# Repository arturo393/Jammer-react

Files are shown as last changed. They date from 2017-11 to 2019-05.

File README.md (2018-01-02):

# Jammer-react
Sistem designed complement the AntiJammer of the Teltonika FMA120 devices.

## Software Protocol

1. Constantemente se revisa JAMIN.
2. If JAMIN == LOW.
 2.1 JAMOUNT  = LOW. por 90 (s)
 2.2 DOUT intercambia entre LOW y abierto duranta 90 (s).
 2.3 Se entra en modo alarma durante 90 (s)
3. Si durante el modo alarma DOORIN == Abierto
 3.1 JAMOUT = LOW durante5 minutos despues que termine el modo alarma

## Documentation
1. Flow diagram of the software.
2. Bitácora
3.

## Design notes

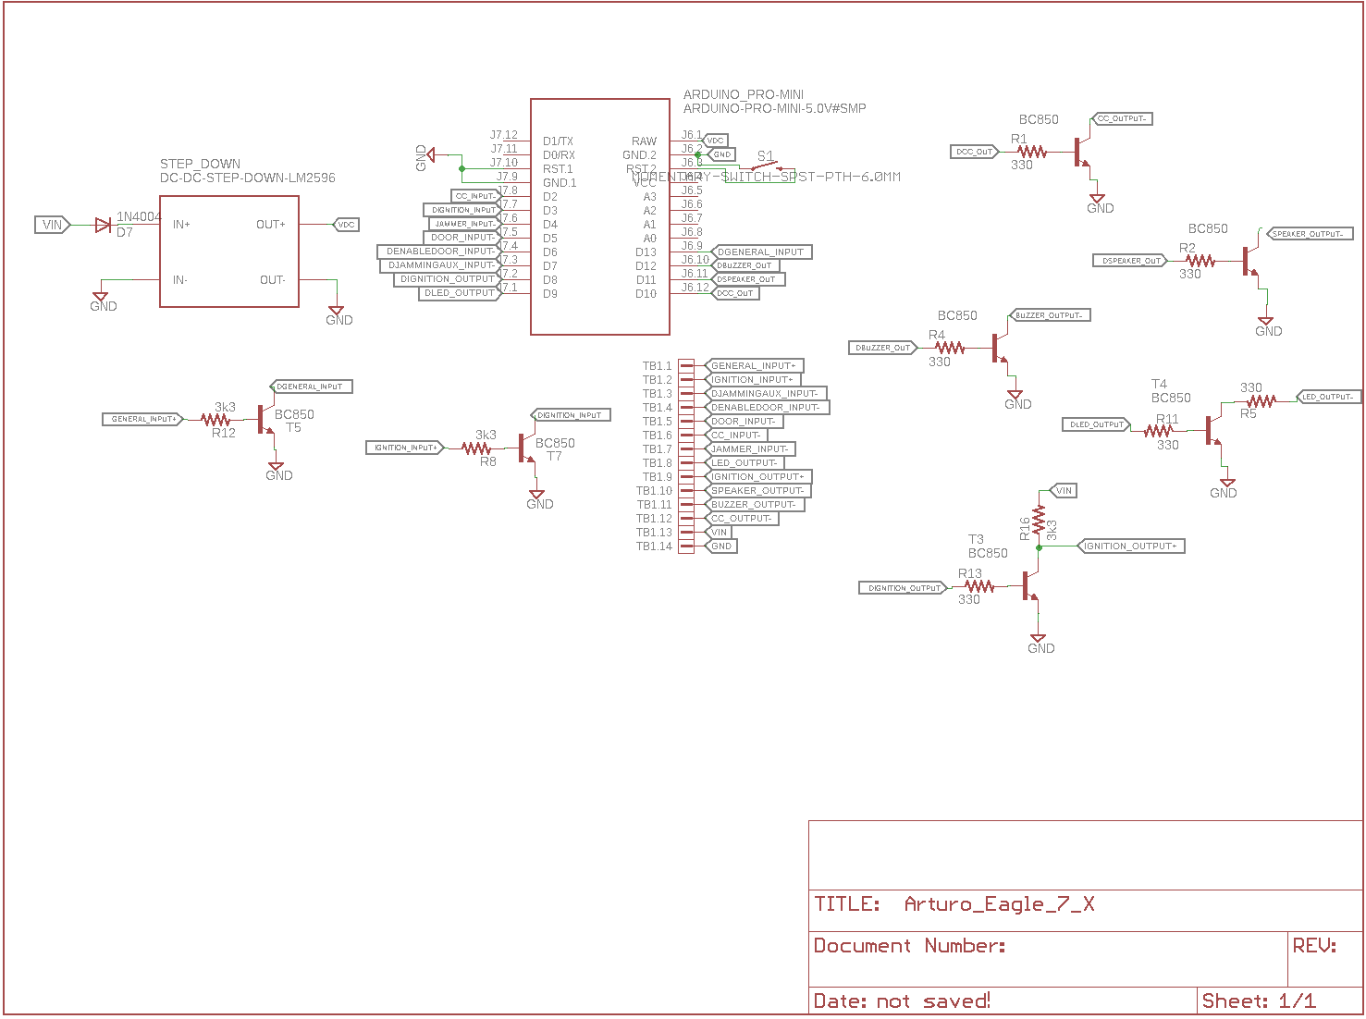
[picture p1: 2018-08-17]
Hardware/v2/circuito.png

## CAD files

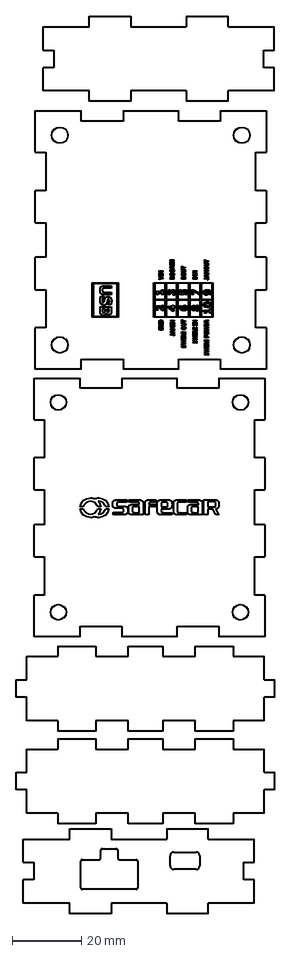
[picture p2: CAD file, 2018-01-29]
case/safecar.dxf
74.6 x 258.8 mm

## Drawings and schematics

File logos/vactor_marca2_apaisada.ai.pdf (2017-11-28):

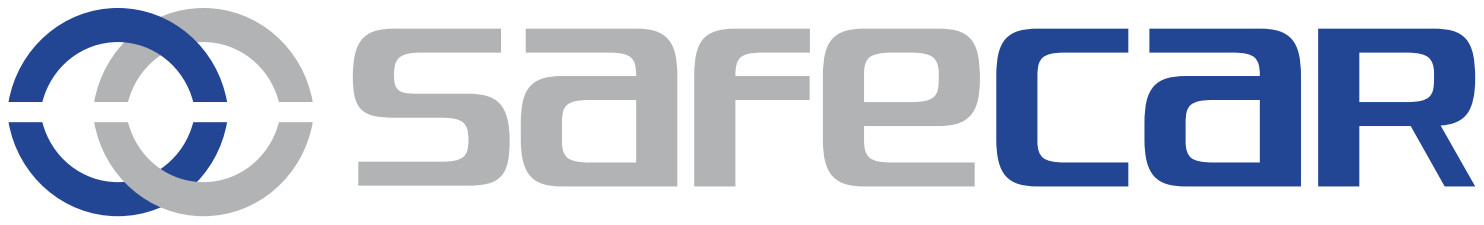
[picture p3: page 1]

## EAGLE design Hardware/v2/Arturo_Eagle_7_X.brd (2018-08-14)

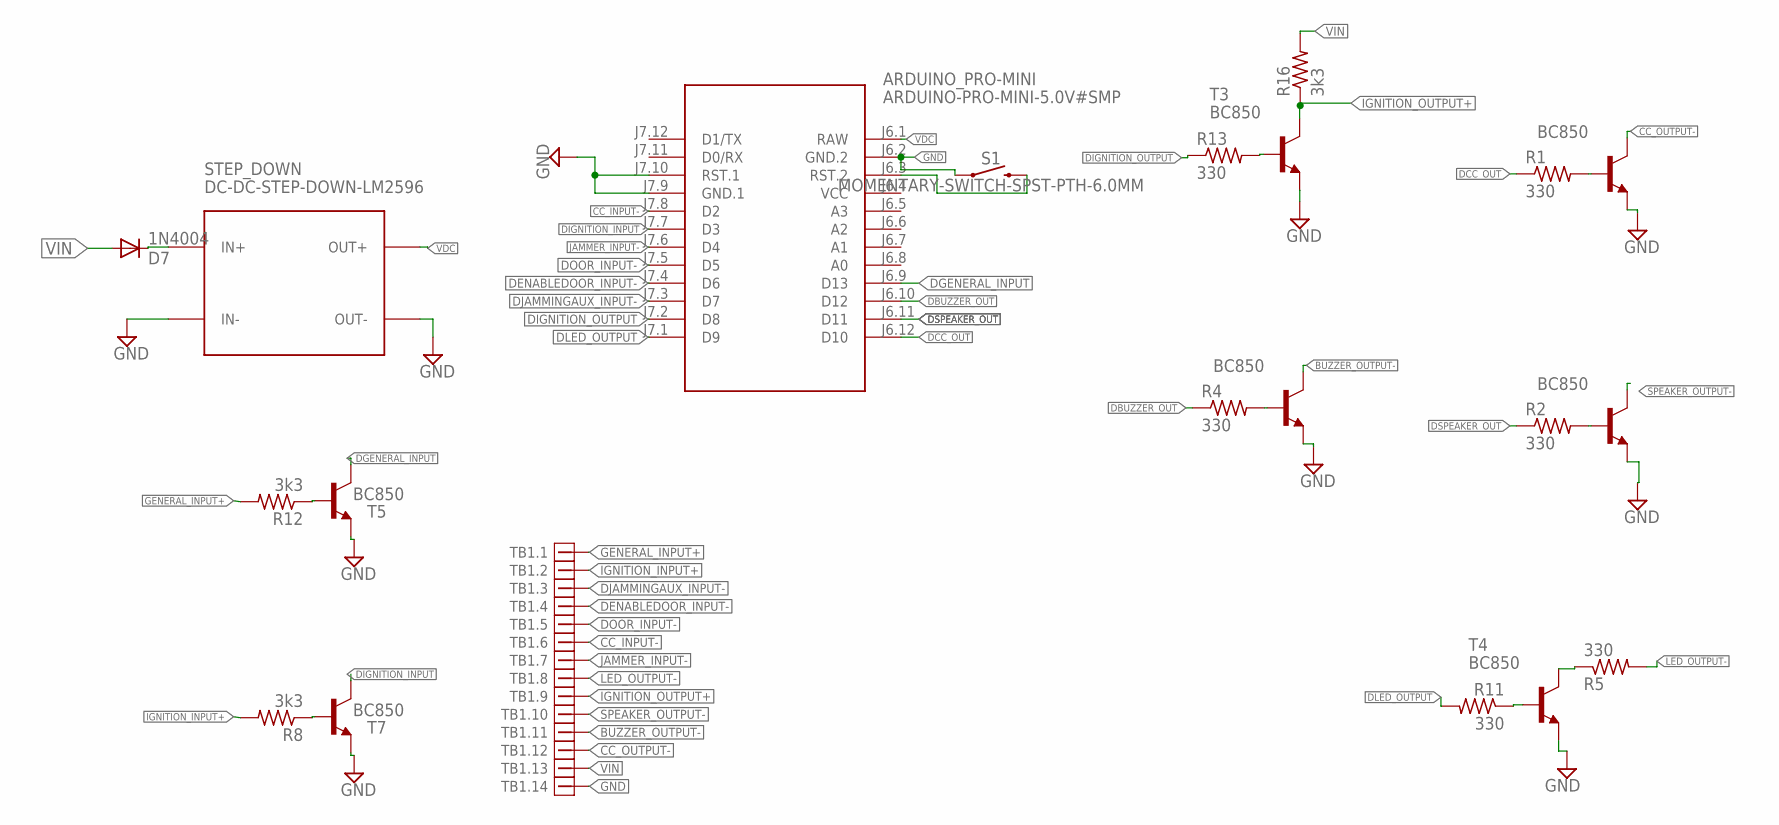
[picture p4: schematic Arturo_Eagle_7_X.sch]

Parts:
ARDUINO_PRO-MINI: ARDUINO-PRO-MINI-5.0V#SMP; ARDUINO-PRO-MINI#SMP
D7: 1N4004; DO41-10
R1, R2, R4, R5, R11, R13: 330; R0805
R8, R12, R16: 3k3; R0805
S1: MOMENTARY-SWITCH-SPST-PTH-6.0MM; TACTILE_SWITCH_PTH_6.0MM
STEP_DOWN: DC-DC-STEP-DOWN-LM2596
T1, T3, T4, T5, T6, T7, T8: BC850; SOT23
TB1: TB_PHOENIX; TERMINAL_BLOCK_14POS

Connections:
BUZZER_OUTPUT-: T6.3 (C), TB1.11, TB1.25
CC_INPUT-: ARDUINO_PRO-MINI.J7.8 (D2), TB1.6, TB1.20
CC_OUTPUT-: T8.3 (C), TB1.12, TB1.26
DBUZZER_OUT: ARDUINO_PRO-MINI.J6.10 (D12), R4.1
DCC_OUT: ARDUINO_PRO-MINI.J6.12 (D10), R1.1
DENABLEDOOR_INPUT-: ARDUINO_PRO-MINI.J7.4 (D6), TB1.4, TB1.18
DGENERAL_INPUT: ARDUINO_PRO-MINI.J6.9 (D13), T5.3 (C)
DIGNITION_INPUT: ARDUINO_PRO-MINI.J7.7 (D3), T7.3 (C)
DIGNITION_OUTPUT: ARDUINO_PRO-MINI.J7.2 (D8), R13.1
DJAMMINGAUX_INPUT-: ARDUINO_PRO-MINI.J7.3 (D7), TB1.3, TB1.17
DLED_OUTPUT: ARDUINO_PRO-MINI.J7.1 (D9), R11.2
DOOR_INPUT-: ARDUINO_PRO-MINI.J7.5 (D5), TB1.5, TB1.19
DSPEAKER_OUT: ARDUINO_PRO-MINI.J6.11 (D11), R2.1
GENERAL_INPUT+: R12.2, TB1.1, TB1.15
GND: ARDUINO_PRO-MINI.J6.2 (GND.2), ARDUINO_PRO-MINI.J7.9 (GND.1), ARDUINO_PRO-MINI.J7.10 (RST.1), S1.1, STEP_DOWN.IN-, STEP_DOWN.OUT-, T1.2 (E), T3.2 (E), T4.2 (E), T5.2 (E), T6.2 (E), T7.2 (E), T8.2 (E), TB1.14, TB1.28
IGNITION_INPUT+: R8.2, TB1.2, TB1.16
IGNITION_OUTPUT+: R16.1, T3.3 (C), TB1.9, TB1.23
JAMMER_INPUT-: ARDUINO_PRO-MINI.J7.6 (D4), TB1.7, TB1.21
LED_OUTPUT-: R5.2, TB1.8, TB1.22
unnamed: R12.1, T5.1 (B)
unnamed: R13.2, T3.1 (B)
unnamed: R1.2, T8.1 (B)
unnamed: R2.2, T1.1 (B)
unnamed: R4.2, T6.1 (B)
unnamed: R5.1, T4.3 (C)
unnamed: ARDUINO_PRO-MINI.J6.3 (RST.2), S1.3 (2)
unnamed: R11.1, T4.1 (B)
unnamed: R8.1, T7.1 (B)
unnamed: D7.C, STEP_DOWN.IN+
SPEAKER_OUTPUT-: T1.3 (C), TB1.10, TB1.24
VCC: ARDUINO_PRO-MINI.J6.4 (VCC)
VDC: ARDUINO_PRO-MINI.J6.1 (RAW), STEP_DOWN.OUT+
VIN: D7.A, R16.2, TB1.13, TB1.27

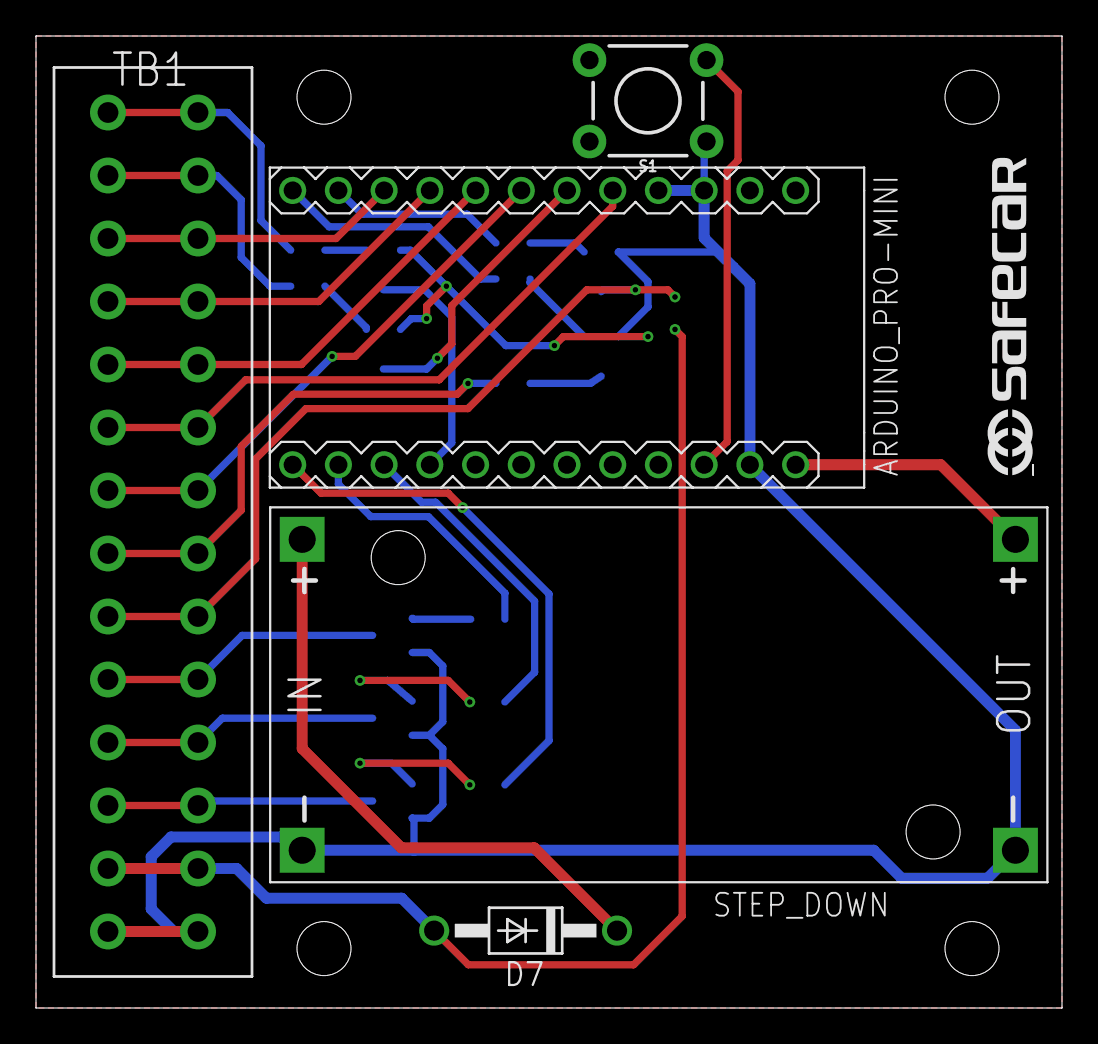
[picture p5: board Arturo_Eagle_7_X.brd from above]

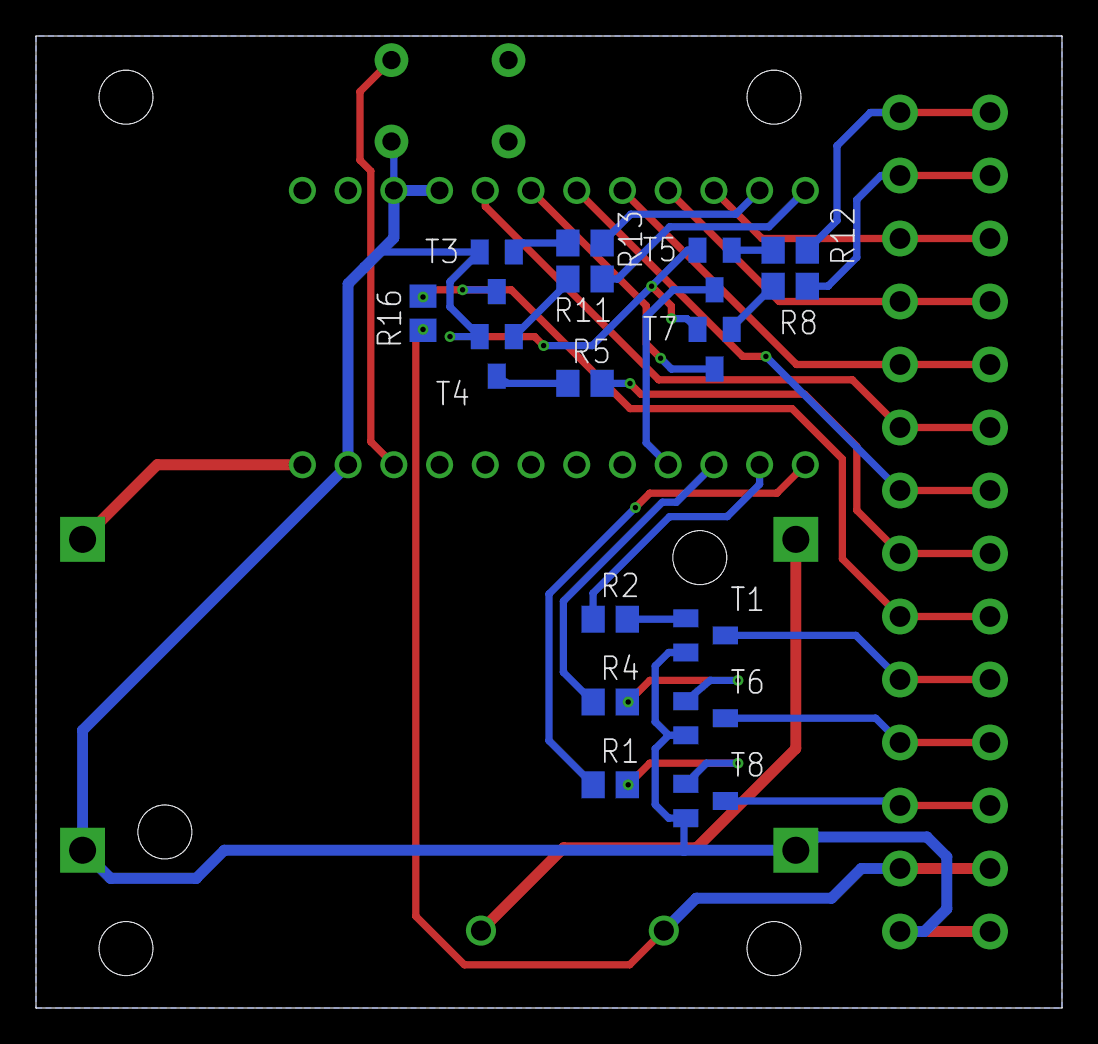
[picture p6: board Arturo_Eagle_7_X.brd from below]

Board: 2 copper layers, 57.0 x 54.0 mm, 21 parts (16 on the bottom side), 32 nets.

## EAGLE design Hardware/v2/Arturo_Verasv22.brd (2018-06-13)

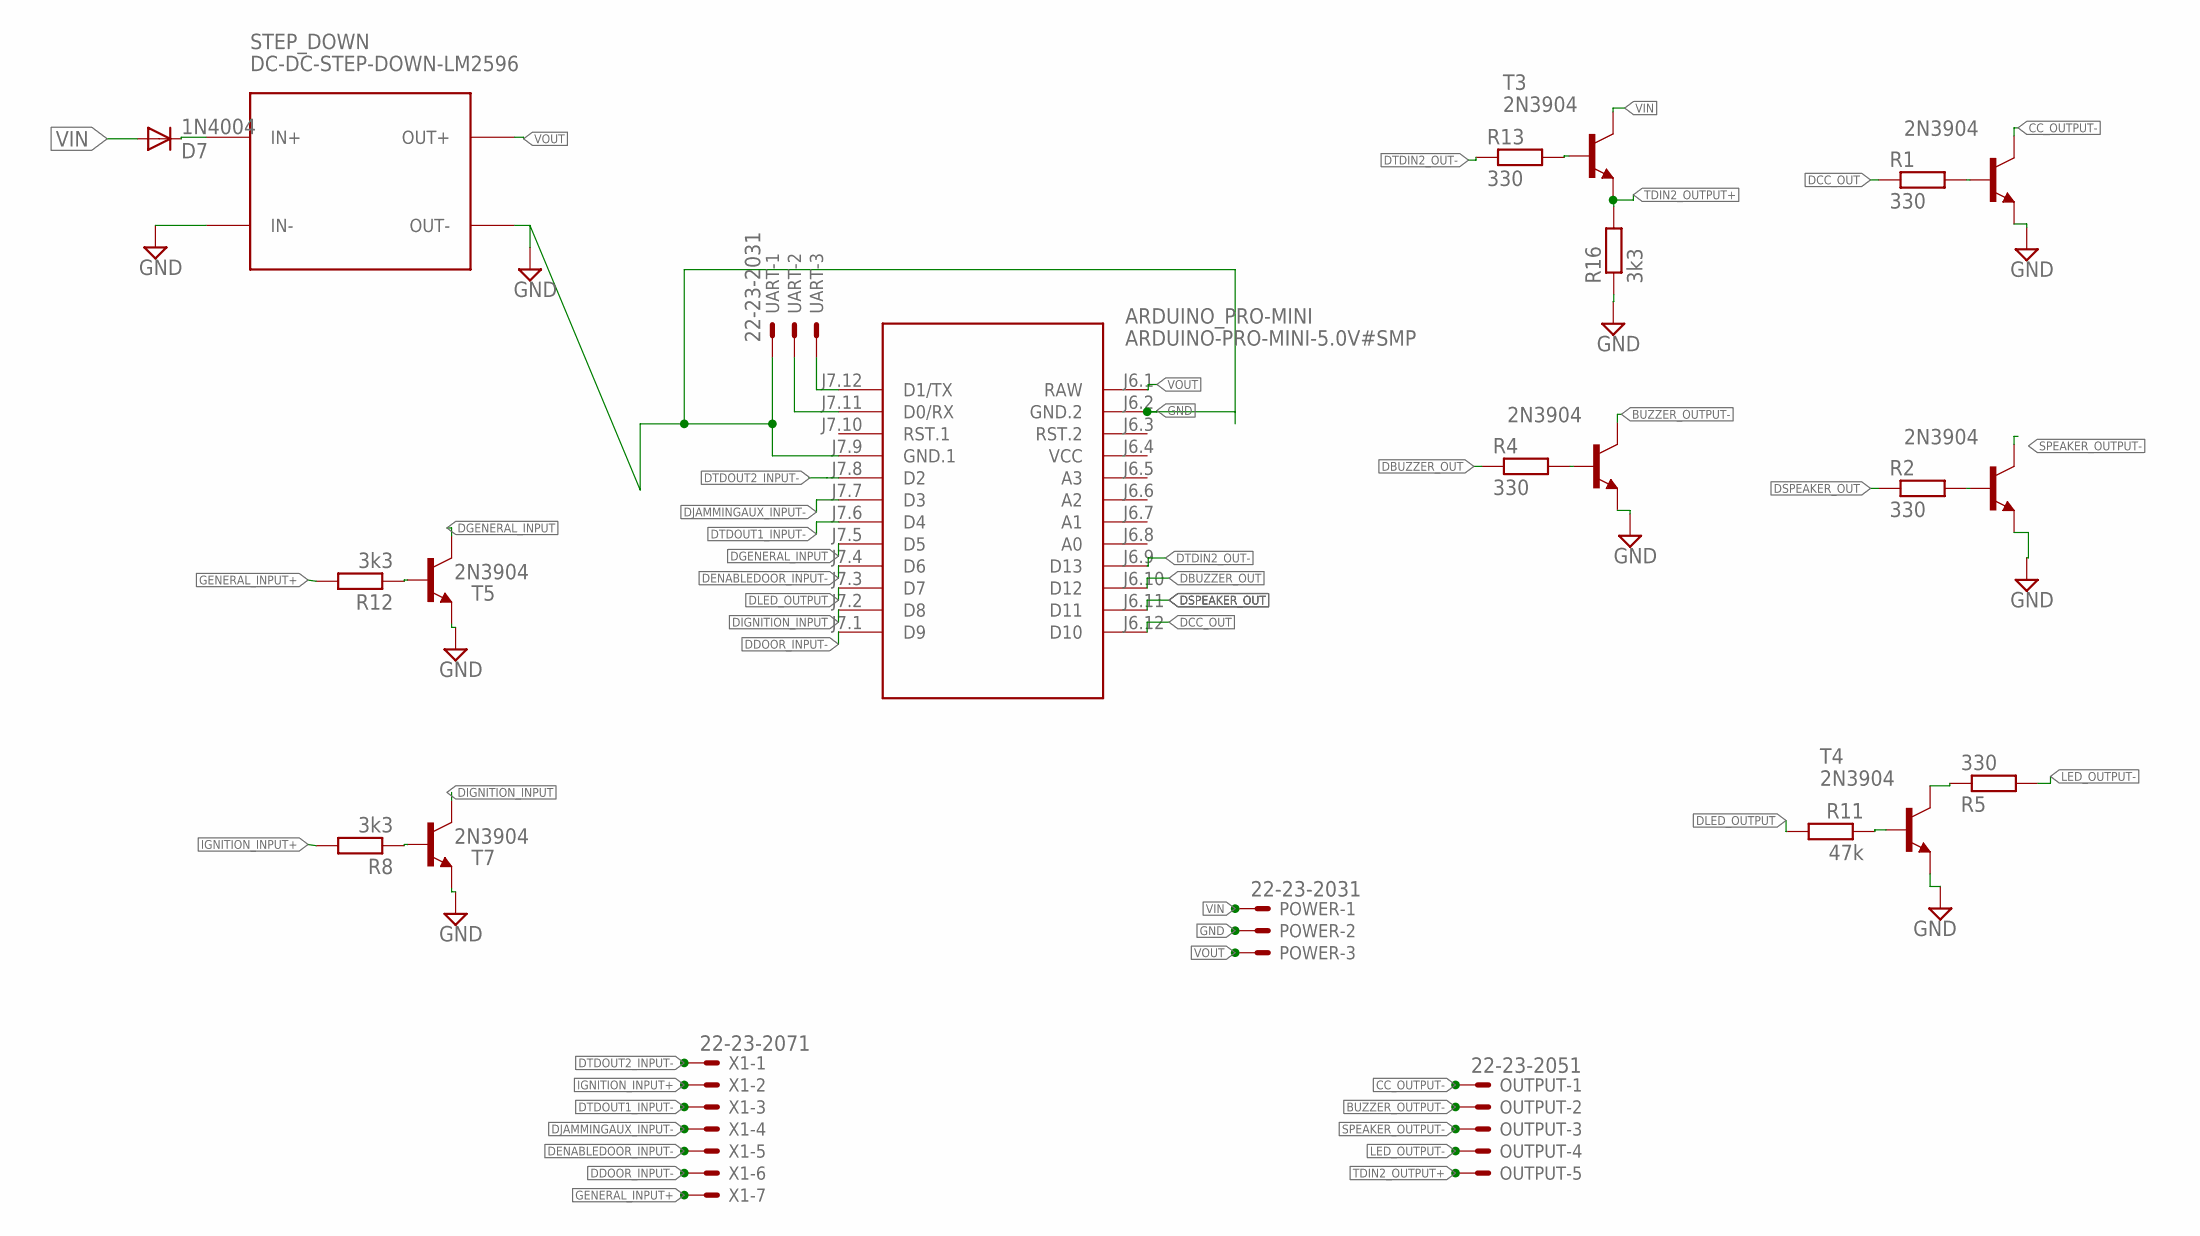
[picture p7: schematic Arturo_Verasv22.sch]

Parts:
ARDUINO_PRO-MINI: ARDUINO-PRO-MINI-5.0V#SMP; ARDUINO-PRO-MINI#SMP
D7: 1N4004; DO41-10
OUTPUT: 22-23-2051
POWER: 22-23-2031
R1, R2, R4, R5, R13: 330; 0204/7
R8, R12, R16: 3k3; 0204/7
R11: 47k; 0204/7
STEP_DOWN: DC-DC-STEP-DOWN-LM2596
T1, T3, T4, T5, T6, T7, T8: 2N3904; TO92
UART: 22-23-2031
X1: 22-23-2071

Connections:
BUZZER_OUTPUT-: OUTPUT.2, T6.1 (C)
CC_OUTPUT-: OUTPUT.1, T8.1 (C)
DBUZZER_OUT: ARDUINO_PRO-MINI.J6.10 (D12), R4.1
DCC_OUT: ARDUINO_PRO-MINI.J6.12 (D10), R1.1
DDOOR_INPUT-: ARDUINO_PRO-MINI.J7.1 (D9), X1.6
DENABLEDOOR_INPUT-: ARDUINO_PRO-MINI.J7.4 (D6), X1.5
DGENERAL_INPUT: ARDUINO_PRO-MINI.J7.5 (D5), T5.1 (C)
DIGNITION_INPUT: ARDUINO_PRO-MINI.J7.2 (D8), T7.1 (C)
DJAMMINGAUX_INPUT-: ARDUINO_PRO-MINI.J7.7 (D3), X1.4
DLED_OUTPUT: ARDUINO_PRO-MINI.J7.3 (D7), R11.2
DSPEAKER_OUT: ARDUINO_PRO-MINI.J6.11 (D11), R2.1
DTDIN2_OUT-: ARDUINO_PRO-MINI.J6.9 (D13), R13.1
DTDOUT1_INPUT-: ARDUINO_PRO-MINI.J7.6 (D4), X1.3
DTDOUT2_INPUT-: ARDUINO_PRO-MINI.J7.8 (D2), X1.1
GENERAL_INPUT+: R12.2, X1.7
GND: ARDUINO_PRO-MINI.J6.2 (GND.2), ARDUINO_PRO-MINI.J7.9 (GND.1), POWER.2, R16.1, STEP_DOWN.IN-, STEP_DOWN.OUT-, T1.3 (E), T4.3 (E), T5.3 (E), T6.3 (E), T7.3 (E), T8.3 (E), UART.1
IGNITION_INPUT+: R8.2, X1.2
LED_OUTPUT-: OUTPUT.4, R5.2
unnamed: R12.1, T5.2 (B)
unnamed: R13.2, T3.2 (B)
unnamed: R1.2, T8.2 (B)
unnamed: R2.2, T1.2 (B)
unnamed: R4.2, T6.2 (B)
unnamed: R5.1, T4.1 (C)
unnamed: ARDUINO_PRO-MINI.J7.12 (D1/TX), UART.3
unnamed: ARDUINO_PRO-MINI.J7.11 (D0/RX), UART.2
unnamed: R11.1, T4.2 (B)
unnamed: R8.1, T7.2 (B)
unnamed: D7.C, STEP_DOWN.IN+
SPEAKER_OUTPUT-: OUTPUT.3, T1.1 (C)
TDIN2_OUTPUT+: OUTPUT.5, R16.2, T3.3 (E)
VIN: D7.A, POWER.1, T3.1 (C)
VOUT: ARDUINO_PRO-MINI.J6.1 (RAW), ARDUINO_PRO-MINI.J6.4 (VCC), POWER.3, STEP_DOWN.OUT+

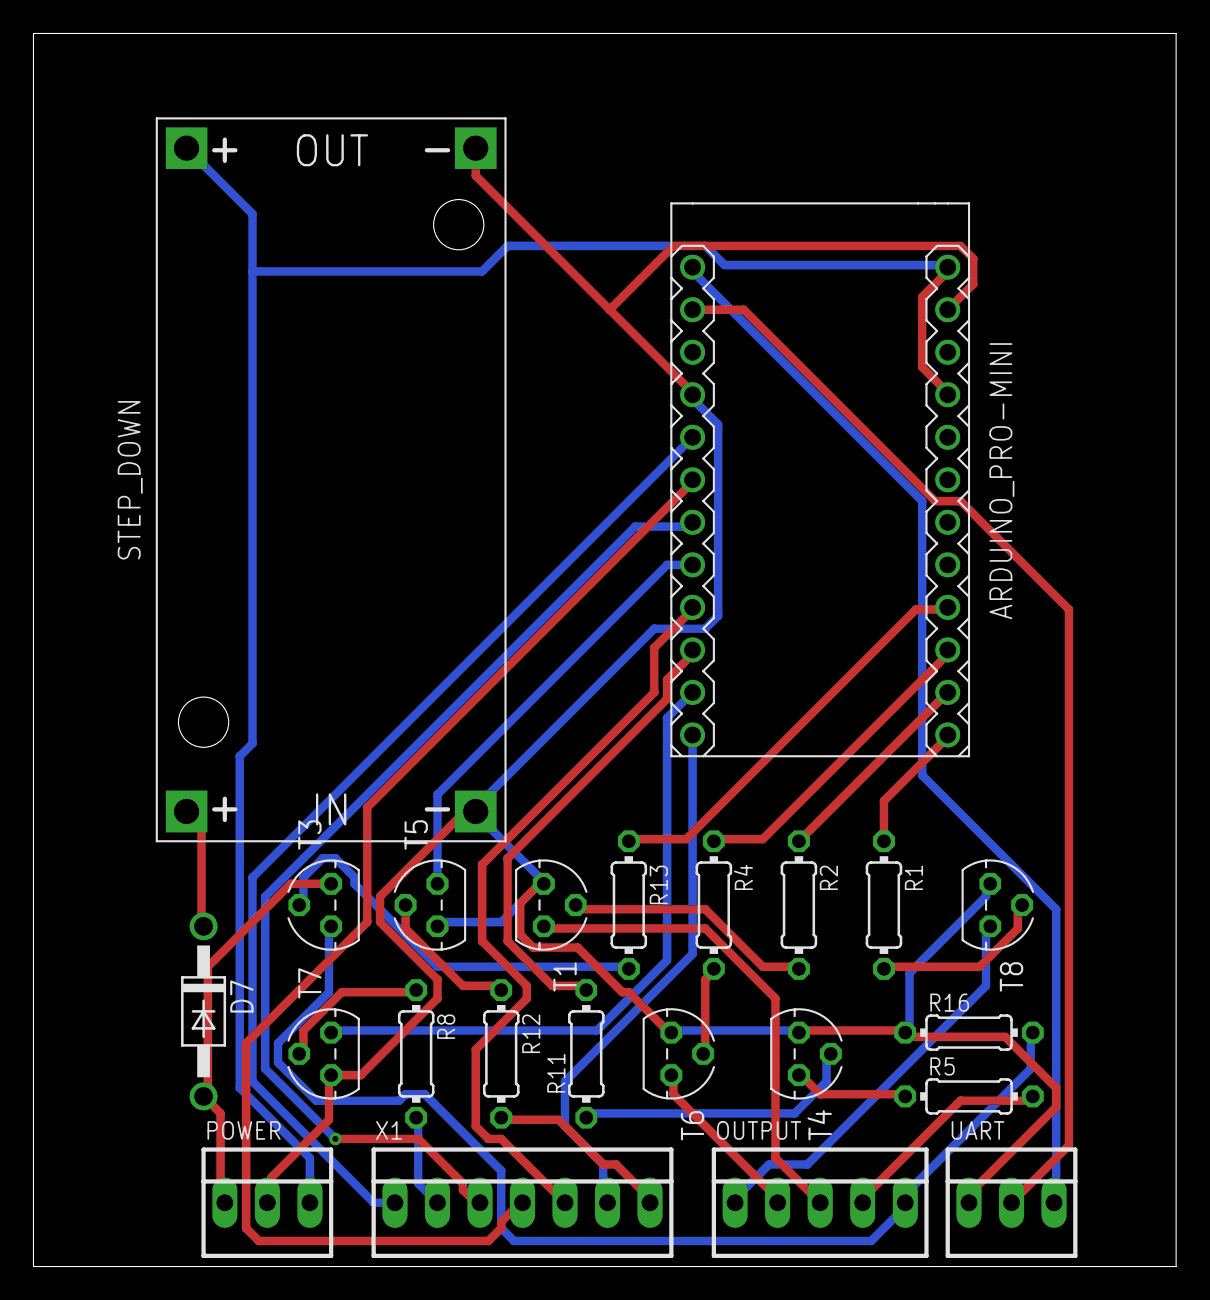
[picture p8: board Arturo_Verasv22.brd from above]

Board: 2 copper layers, 68.2 x 73.7 mm, 23 parts (0 on the bottom side), 33 nets.

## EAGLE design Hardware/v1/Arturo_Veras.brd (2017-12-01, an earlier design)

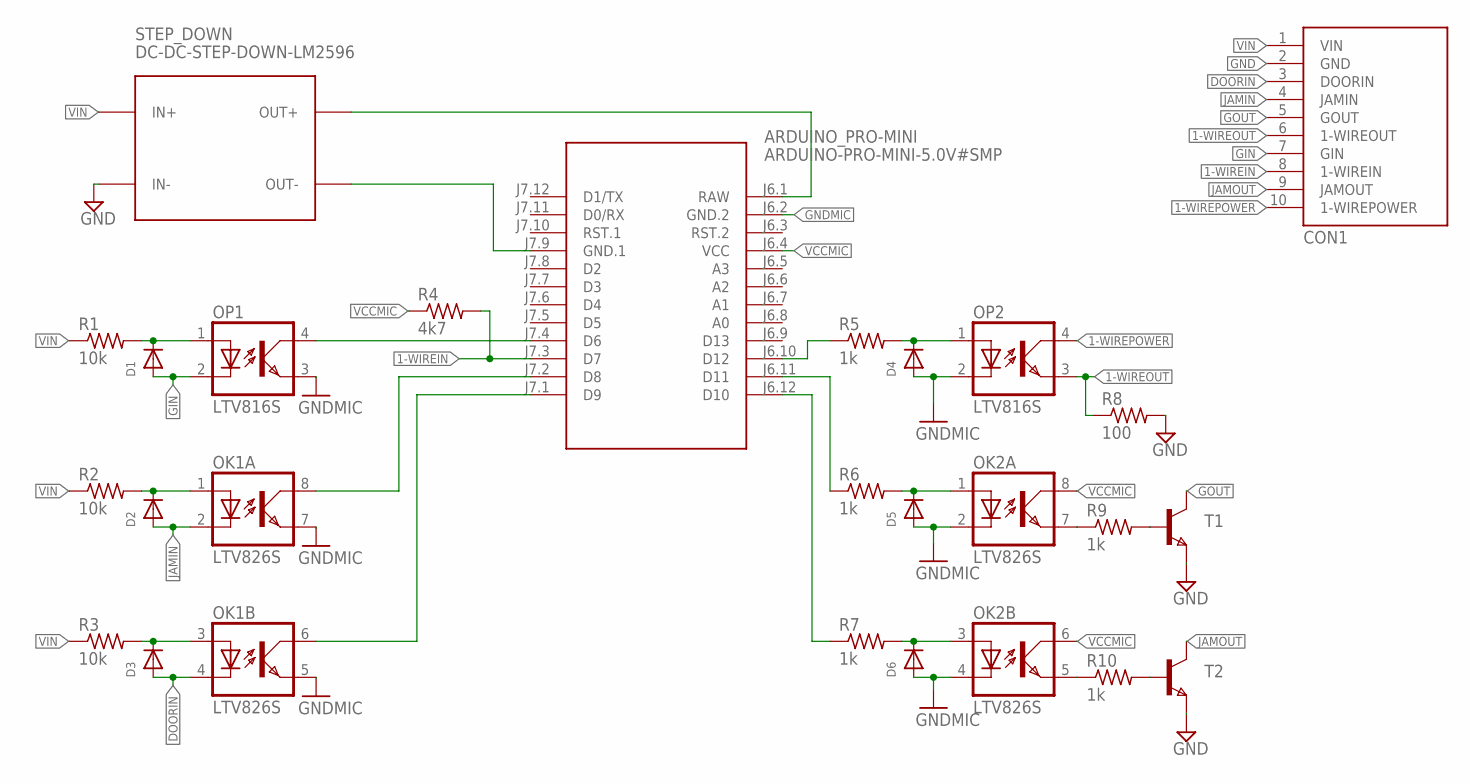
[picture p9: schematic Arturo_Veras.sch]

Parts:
ARDUINO_PRO-MINI: ARDUINO-PRO-MINI-5.0V#SMP; ARDUINO-PRO-MINI#SMP
CON1: TIN_HEADER_10POS; MICRO_MATE_N_LOK_TRUEHOLE_10POS
D1, D2, D3, D4, D5, D6: DIODESOD-323F; SOD-323F
OK1, OK2: LTV826S; DIL8-SMD
OP1, OP2: LTV816S; SMD4
R1, R2, R3: 10k; R0603
R4: 4k7; R0603
R5, R6, R7, R9, R10: 1k; R0603
R8: 100; R0603
STEP_DOWN: DC-DC-STEP-DOWN-LM2596
T1, T2: PBSS4360Z; SOT223

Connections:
1-WIREIN: ARDUINO_PRO-MINI.J7.3 (D7), CON1.8 (1-WIREIN), R4.2
1-WIREOUT: CON1.6 (1-WIREOUT), OP2.3 (EMIT), R8.1
1-WIREPOWER: CON1.10 (1-WIREPOWER), OP2.4 (COL)
DOORIN: CON1.3 (DOORIN), D3.A, OK1.4 (C)
GIN: CON1.7 (GIN), D1.A, OP1.2 (C)
GND: CON1.2 (GND), R8.2, STEP_DOWN.IN-, T1.3 (E), T2.3 (E)
GNDMIC: ARDUINO_PRO-MINI.J6.2 (GND.2), D4.A, D5.A, D6.A, OK1.5 (EMIT), OK1.7 (EMIT), OK2.2 (C), OK2.4 (C), OP1.3 (EMIT), OP2.2 (C)
GOUT: CON1.5 (GOUT), T1.2 (C), T1.4 (C)
JAMIN: CON1.4 (JAMIN), D2.A, OK1.2 (C)
JAMOUT: CON1.9 (JAMOUT), T2.2 (C), T2.4 (C)
unnamed: ARDUINO_PRO-MINI.J7.9 (GND.1), STEP_DOWN.OUT-
unnamed: ARDUINO_PRO-MINI.J6.1 (RAW), STEP_DOWN.OUT+
unnamed: ARDUINO_PRO-MINI.J7.4 (D6), OP1.4 (COL)
unnamed: D1.C, OP1.1 (A), R1.2
unnamed: ARDUINO_PRO-MINI.J6.10 (D12), R5.1
unnamed: D2.C, OK1.1 (A), R2.2
unnamed: ARDUINO_PRO-MINI.J7.2 (D8), OK1.8 (COL)
unnamed: D3.C, OK1.3 (A), R3.2
unnamed: D4.C, OP2.1 (A), R5.2
unnamed: ARDUINO_PRO-MINI.J7.1 (D9), OK1.6 (COL)
unnamed: OK2.7 (EMIT), R9.1
unnamed: ARDUINO_PRO-MINI.J6.11 (D11), R6.1
unnamed: D5.C, OK2.1 (A), R6.2
unnamed: ARDUINO_PRO-MINI.J6.12 (D10), R7.1
unnamed: D6.C, OK2.3 (A), R7.2
unnamed: OK2.5 (EMIT), R10.1
unnamed: R9.2, T1.1 (B)
unnamed: R10.2, T2.1 (B)
VCCMIC: ARDUINO_PRO-MINI.J6.4 (VCC), OK2.6 (COL), OK2.8 (COL), R4.1
VIN: CON1.1 (VIN), R1.1, R2.1, R3.1, STEP_DOWN.IN+

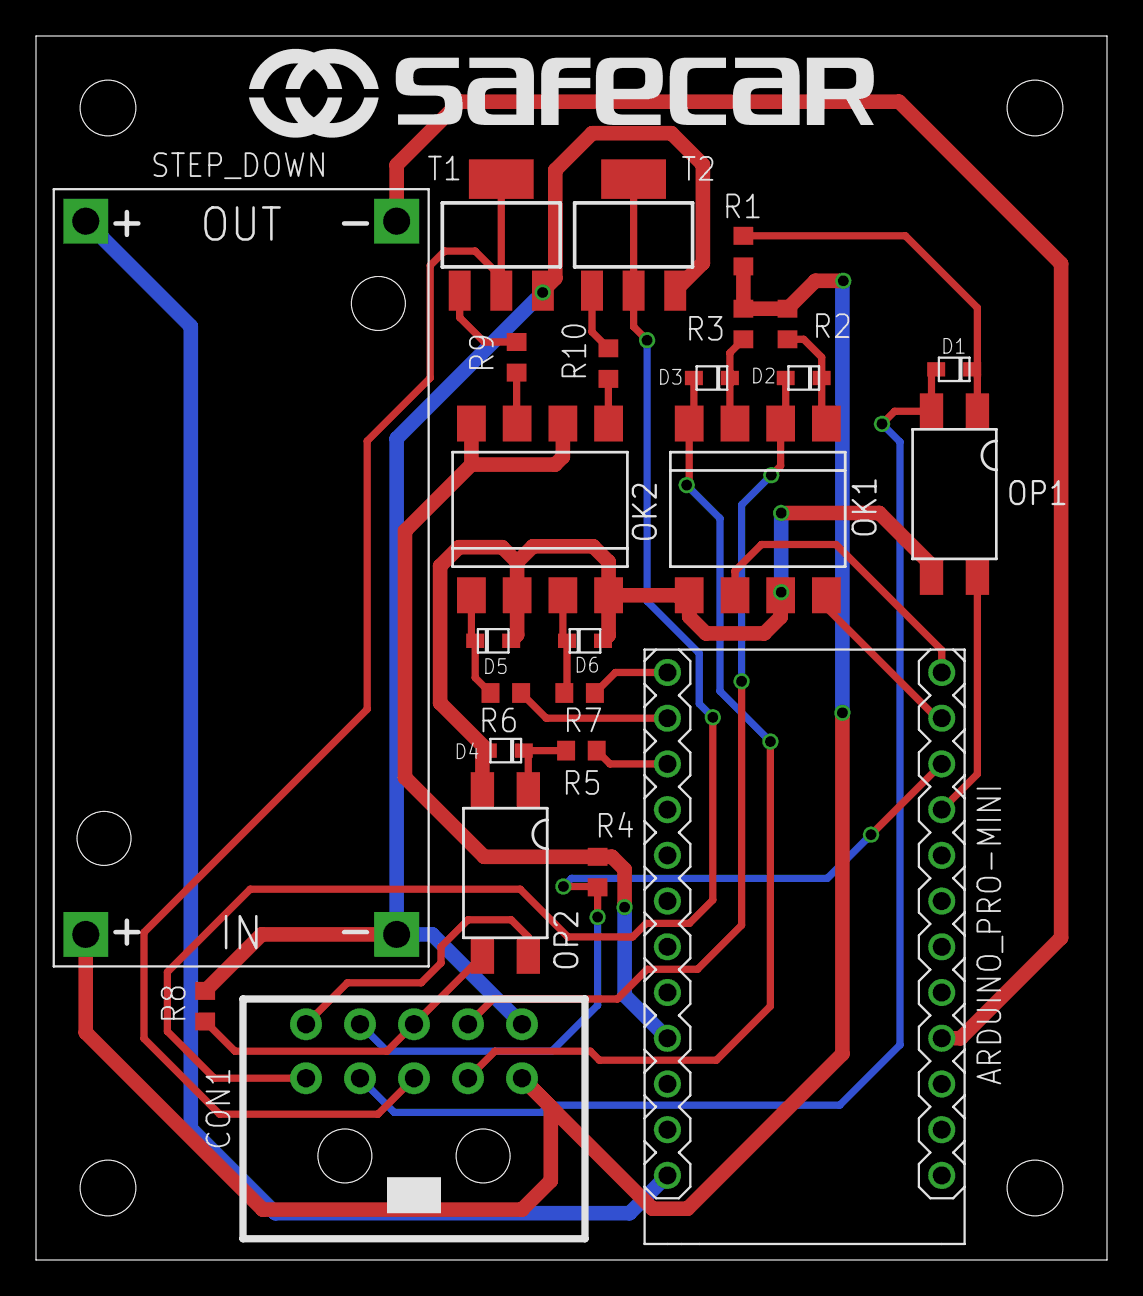
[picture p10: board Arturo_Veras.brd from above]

Board: 2 copper layers, 59.5 x 68.0 mm, 25 parts (0 on the bottom side), 30 nets.

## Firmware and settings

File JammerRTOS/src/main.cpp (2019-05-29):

#include <Arduino.h>
#include <Arduino_FreeRTOS.h>
#include <avr/wdt.h>
#include <EEPROM.h>
#include "timers.h"

const char VERSION[] = "2.2";

//#define DEBUG 1
//#define PRINT_DOORSTATUS
//#define PRINT_PROTOCOL_STATUS
//#define PRINT_IGNITION_STATUS
//#define PRINT_JAMMING_STATUS
//#define PRINT_PASSWORD_STATUS
//#define PRINT_CC_STATUS
//#define PRINT_DISABLE_STATUS

//#define PROTOCOLFREE_BYTES
//#define DISABLE_FREE_BYTES
//#define IGNITION_FREE_BYTES
//#define DOOR_FREE_BYTES
//#define PASSWORD_FREE_BYTES2
//#define CC_FREE_BYTES
//#define JAMMING_FREE_BYTES
/* Useful Constants */
#define SECS_PER_MIN  (60UL)
#define SECS_PER_HOUR (3600UL)
#define SECS_PER_DAY  (SECS_PER_HOUR * 24L)

/* Useful Macros for getting elapsed time */
#define numberOfSeconds(_time_) (_time_ % SECS_PER_MIN)
#define numberOfMinutes(_time_) ((_time_ / SECS_PER_MIN) % SECS_PER_MIN)
#define numberOfHours(_time_) (( _time_% SECS_PER_DAY) / SECS_PER_HOUR)
#define elapsedDays(_time_) ( _time_ / SECS_PER_DAY)


// inputs
#define CCDisable              2      // Enable/disable jamming detection HIGH = on & LOW = off
#define IgnitionPin            3  // (with pull down resistor) Engine power HIGH = on & LOW = off
#define JamDetectionPin        4
#define DoorPin                5     // Door sensor  HIGH = open / LOW = close
#define EnableDoorPin          6
#define JamDetectionAuxPin     7
#define LedPin                 9
#define CCPin                  10    // Corta corriente HIGH = shutdown / LOW = normal
#define BuzzerPin              14
#define DoorPositivePin        15
#define EngineStatusPin        8    // Jamming alert ping HIGH =

#define StatePin              16   // 10 Protocol block - 11 suspended

#define TIME_AFTER_START       15
#define TIME_AFTER_STOP        10
#define TIME_TO_STOP_ENGINE    40
#define TIME_TO_OPEN_DOOR      30
#define DOOR_ENABLE_SECONDS    7
#define NOTIFICATION_TIME      30
#define TIME_AFTER_OPEN_DOOR   60 // secs after the door was opened
#define TIME_JAMMING_SECURE    120
#define TIME_JAMMING_HANG      30*SECS_PER_MIN
//#define TIME_JAMMING_HANG      3*SECS_PER_MIN

#define TIME_JAMMING_AFTER_SECURE 120

#define NORMAL_STATE   1        /* cirtcuit normal state */
#define BLOCKED_STATE  2        /* CC avtivated sate */
#define SUSPEND_STATE  3        /* CC deactivated and all the task suspended */
#define JAMMED_STATE   4
#define PHONE_STATE    5
#define UNKNOWN_STATE 69

#define ID 5
int stateAddress = 20;

#define PASSLENGTH 6
#define DEVICE_ID              001
//#define BAUDRATE               38400
#define BAUDRATE               9600

/** the current address in the EEPROM (i.e. which byte we're going to write to next) **/
int address = 0;

TaskHandle_t cc_handler;
TaskHandle_t jammer_handler;
TaskHandle_t disable_handler;
TaskHandle_t protocol_handler;
TaskHandle_t ignition_handler;
TaskHandle_t door_handler;


TimerHandle_t xTimerNotification;

void time(long val);
void printDigits(byte digits);
int checkPinStatus(uint8_t _pin, uint8_t lastButtonState);
void keyGenerator(char * _temp);
int8_t readSerialBluetooth(char *_reading);
void bluetoothInit( );
int8_t sendATCmd(char _cmd[],char *_response);
void suspendOperationalTasks();
void restartHW();
void suspendTasks();

void vTimerCallback( TimerHandle_t xTimer );

static void vProtocolTask(void *pvParameters);
static void vDisableTask(void *pvParameters);
static void vIgnitionNotification(void *pvParameters);
static void vJammingTask(void *pvParameters);
static void vCCTask(void *pvParameters);
static void vDoorStatusCheckTask(void *pvParameters);

void vApplicationMallocFailedHook( void );
void vApplicationStackOverflowHook( void );
//---------------------------------------------------------------------
unsigned long _time = 0;
unsigned long _last_time = 0;


void setup() {
  Serial1.begin(9600);

  #ifdef DEBUG
  // initialize serial communication at 9600 bits per second:
  Serial.begin(9600);

  while (!Serial) {
  ; // wait for serial port to connect. Needed for native USB
  }
  #endif

  //wdt_enable(WDTO_4S);

  xTaskCreate(vDisableTask,"Disable",configMINIMAL_STACK_SIZE+50+20,NULL,tskIDLE_PRIORITY,&disable_handler);
  xTaskCreate(vCCTask,"CC",configMINIMAL_STACK_SIZE+62-32+10, NULL, tskIDLE_PRIORITY,&cc_handler);
  xTaskCreate(vIgnitionNotification,"Ignition",configMINIMAL_STACK_SIZE+31,NULL,tskIDLE_PRIORITY,&ignition_handler);
  xTaskCreate(vProtocolTask,"Protocol",configMINIMAL_STACK_SIZE+40,NULL,tskIDLE_PRIORITY,&protocol_handler);
  xTaskCreate(vJammingTask,"Jamming",configMINIMAL_STACK_SIZE+40, NULL, tskIDLE_PRIORITY , &jammer_handler);
  xTaskCreate(vDoorStatusCheckTask,"Doorpos",configMINIMAL_STACK_SIZE+40, NULL, tskIDLE_PRIORITY ,&door_handler);

  xTimerNotification = xTimerCreate(
    "Timer",
    configTICK_RATE_HZ*10,
    pdTRUE,
    (void *) 0,
    vTimerCallback
  );

  pinMode(StatePin, OUTPUT);
  pinMode(CCPin, OUTPUT);
  pinMode(LedPin, OUTPUT);
  pinMode(BuzzerPin, OUTPUT);
  pinMode(EnableDoorPin, INPUT_PULLUP);
  pinMode(DoorPin, INPUT_PULLUP);
  pinMode(JamDetectionPin, INPUT_PULLUP);
  pinMode(DoorPositivePin, INPUT_PULLUP);
  pinMode(IgnitionPin, INPUT_PULLUP);
  pinMode(CCDisable, INPUT_PULLUP);

}

  //------------------------------------------------------------------------------
  // WARNING idle loop has a very small stack (configMINIMAL_STACK_SIZE)
  // loop must never block
  void loop() {
  }

//-----------------------------------------------------------------------------
/* This task activate send notitfication to activate CC ON using
 * door notification button satate detection */
static void vProtocolTask(void *pvParameters)
{

  uint32_t ulNotifiedValue = 0x00;            /* notified recieve value*/
  TickType_t xFrequency = pdMS_TO_TICKS(10);  /* frecuency for waiting notification */
  #ifdef PROTOCOL_FREE_BYTES
  UBaseType_t uxHighWaterMark;
  #endif                   /* counter for displaying one time */
  for(;;)
   {

    #ifdef PROTOCOL_FREE_BYTES
    Serial.print("ProtocolFreeWords ");
    uxHighWaterMark = uxTaskGetStackHighWaterMark(protocol_handler);
    Serial.println(uxHighWaterMark);
    vTaskDelay(pdMS_TO_TICKS(5000));
    #endif

    xTaskNotifyWait( 0x00,      /* Don't clear any notification bits on entry. */
    0xF0, /* Reset second word of the notification value to 0 on exit. */
    &ulNotifiedValue, /* Notified value pass out in ulNotifiedValue. */
    xFrequency  );  /* Block indefinitely. */

    /* recieve engine off  notification from vIgnitionNotification */
    if( ( ulNotifiedValue == 0x02  ) )
    {
      digitalWrite(LedPin, LOW);
      xFrequency = portMAX_DELAY;
      #ifdef PRINT_PROTOCOL_STATUS
      Serial.print("Secure Protocol Stoped!\n");
      #endif
    }

    /* recieve engine on  notification from vIgnitionNotification */
    if( ( ulNotifiedValue == 0x01 ) )
    {
      digitalWrite(LedPin,HIGH);

      #ifdef PRINT_PROTOCOL_STATUS
      if(k == 0)
        Serial.print("Secure Protocol Started!\n");
      k = 1;
      #endif
      xFrequency = pdMS_TO_TICKS(10);
      /* if button is pressed */
      if(digitalRead(EnableDoorPin) == LOW){
        #ifdef PRINT_PROTOCOL_STATUS
        Serial.print("vProtcolTask Suspended  ");
        Serial.print(TIME_TO_OPEN_DOOR);
        Serial.print(" seconds ");
        #endif

        /* send disable door open detection notification*/
        xTaskNotify(door_handler,0x01, eSetValueWithOverwrite);
        int ecount = 0;      /* EnableDoorPin counter */
        int i = 0;           /* counter for print */
        /* suspend vProtcolTask for TIME_TO_OPEN_DOOR seconds */
        do
        {
          #ifdef PRINT_PROTOCOL_STATUS
          if(i % 10 == 0)
          {
           Serial.print((TIME_TO_OPEN_DOOR+ecount)-i);
           Serial.print(" ");
          }
          #endif

          digitalWrite(LedPin,LOW);
          vTaskDelay(pdMS_TO_TICKS(1000));
          i++;
          digitalWrite(LedPin,HIGH);
          vTaskDelay(pdMS_TO_TICKS(1000));
          i++;
          /* if button is pressed , add 20 seconds more to te suspended task*/
          if( (digitalRead(EnableDoorPin) == LOW) && (ecount <= 60 ) )
              ecount += 20;

          } while(i < (TIME_TO_OPEN_DOOR + ecount) );

          /* send disable door open detection notification*/
          xTaskNotify(door_handler,0x00, eSetValueWithOverwrite);
          #ifdef PRINT_PROTOCOL_STATUS
          Serial.println("vProtocolTask Resumed ");
          #endif
        } /* end EnableDoorPin */
      } /* end secure protocol */


     /* if door is open redunce */
     #ifndef DOORSENSOR
     if(digitalRead(DoorPin) == LOW || digitalRead(DoorPositivePin) == LOW)
     {
     #endif
     #ifdef DOORSENSOR
     if(digitalRead(DoorPin) == HIGH)
     {
     #endif
      /* if door notification is open */
      if(  ulNotifiedValue == 0x11 )
      {
       digitalWrite(LedPin, LOW);
       #ifdef PRINT_PROTOCOL_STATUS
       Serial.print("vProtocolTask Suspended ");
       #endif

       /* suspend task for TIME_AFTER_OPEN_DOOR seconds */
       for(int j = 0; j < TIME_AFTER_OPEN_DOOR ; j++)
       {
        #ifdef PRINT_PROTOCOL_STATUS
        if (j % 10 == 0)
        {
          Serial.print(j);
          Serial.print(" ");
        }
        #endif
        vTaskDelay(pdMS_TO_TICKS(500));
        digitalWrite(LedPin,HIGH);
        vTaskDelay(pdMS_TO_TICKS(500));
        digitalWrite(LedPin,LOW);
      }

        digitalWrite(LedPin,LOW);
        EEPROM.update(stateAddress, BLOCKED_STATE);
        #ifdef PRINT_PROTOCOL_STATUS
        Serial.println("vCCTask notification");
        #endif

        /* send CC on notification */
        xTaskNotify(cc_handler,0x03, eSetValueWithOverwrite );
        digitalWrite(StatePin, HIGH);
        Serial1.print("s");
        Serial1.println(BLOCKED_STATE);
        vTaskDelay(pdMS_TO_TICKS(TIME_AFTER_STOP*1000));
        ulNotifiedValue = 0x02;
      } /* end door open and protocol notification */
    } /* end door open redundace detection*/
  } /* end for(;;) */
}

void vTimerCallback( TimerHandle_t xTimer )
 {

    configASSERT( pxTimer );
    Serial1.print("s");
    Serial1.println(EEPROM.read(stateAddress));

 }
//-----------------------------------------------------------------------------
/* This task activate send notitfication to activate CC ON using
 * door notification and jamming detection */
static void vDisableTask(void *pvParameters)
 {
  bool _last_state     = HIGH;              /* CCDisable pin last state*/
  bool _reading_state  = HIGH;              /* CCDisable pin reading state */
  bool _current_state  = HIGH;              /* CCDisable pin current state */
  TickType_t lastDebounceTime = 0;                 /* the last time the EnableDoorPin pin was toggled */
  TickType_t debounceDelay = pdMS_TO_TICKS(500);   /* the debounce time */
  int16_t ecount = 0;                           /*counter for EnableDoorPin on*/
  int16_t elimit  = 0;                          /* limit for vCCTask notfiication*/

  char readingString[10];              /* reading string from bluetooth */


  #ifdef PASSWORD_FREE_BYTES
  UBaseType_t uxHighWaterMark;
  #endif

  bluetoothInit();
  int8_t savedState = EEPROM.read(stateAddress);

  xTimerStart(xTimerNotification,0);
  Serial1.println("End blueconfig");
  for  (;;) {

    if( savedState  == NORMAL_STATE )
      {
        xTaskNotify(cc_handler,0x01, eSetValueWithOverwrite );
        vTaskDelay(configTICK_RATE_HZ);
        Serial1.print("s");
        Serial1.println(NORMAL_STATE);
        savedState = 0;
      }
    else
      if(savedState == SUSPEND_STATE)
      {
        xTaskNotify(cc_handler,0x04, eSetValueWithOverwrite );
        vTaskDelay(configTICK_RATE_HZ);
        Serial1.print("s");
        Serial1.println(SUSPEND_STATE);
        savedState = 0;
      }
      else
        if(savedState == BLOCKED_STATE)
        {
          xTaskNotify(cc_handler,0x03, eSetValueWithOverwrite );
          digitalWrite(StatePin, HIGH);
          vTaskDelay(configTICK_RATE_HZ);
          Serial1.print("s");
          Serial1.println(BLOCKED_STATE);
          savedState = 0;
        }
        else
        if(savedState == JAMMED_STATE)
          {
            xTaskNotify(cc_handler,0x02, eSetValueWithOverwrite );
            vTaskDelay(configTICK_RATE_HZ);
            Serial1.print("s");
            Serial1.println(JAMMED_STATE);
            savedState = 0;
          }
        else{
        //  Serial1.println("\nUndefined State");
          savedState = 10;
        }

    #ifdef DISABLE_FREE_BYTES
    Serial.print("DisableFreeWords ");
    uxHighWaterMark = uxTaskGetStackHighWaterMark(disable_handler);
    Serial.println(uxHighWaterMark);
    vTaskDelay(pdMS_TO_TICKS(5000));
    #endif

    ecount = 0;
    elimit = random(45,120);

    /* repeat while button is pressed */
    while(digitalRead(EnableDoorPin) == LOW)
    {
     #ifdef PRINT_DISABLE_STATUS
     if((elimit-ecount) % 20  == 0)
     {
      Serial.print(elimit-ecount);
      Serial.print(" ");
     }
     #endif
    /* when reach the limit */
    if(ecount == elimit)
    {
      /* if already suspended */
      if (EEPROM.read(stateAddress) == SUSPEND_STATE)
      {
        vTaskResume(cc_handler);
        Serial1.println("\nNormal");
        xTaskNotify(cc_handler,0x10, eSetValueWithOverwrite );
        ecount = 0;
      }
      /* if not suspended */
      else
      {
        xTaskNotify(cc_handler,0x04, eSetValueWithOverwrite );
        Serial1.println("\nSuspend");
        ecount = 0;
      }
    }

    /* count every 1 second */
    vTaskDelay(pdMS_TO_TICKS(100));
    ecount++;
  } /* end while EnableDoorPin */


  /* CCDisable pin readings every 10 ms */
  vTaskDelay(pdMS_TO_TICKS(10));
  _reading_state = digitalRead(CCDisable);

  /* if CCDisable any change update the debounce time */
  if(_reading_state != _last_state )
    lastDebounceTime = xTaskGetTickCount();

  /* if there is no change after debounceDelay */
  if (( xTaskGetTickCount() - lastDebounceTime) > debounceDelay){
    /* if the current reading is different from lastnotification value */
    if (_reading_state != _current_state )
    {
      _current_state = _reading_state;

      #ifdef PRINT_DISABLE_STATUS
      if( _reading_state == HIGH )
        Serial.println("CCDisable HIGH");
      else
        Serial.println("CCDisable LOW");
      #endif

      /* if CCDisable is HIGH then CC OFF */
      if(_current_state == HIGH)
      {
        /* send CC OFF notification */
        xTaskNotify(cc_handler,0x10, eSetValueWithOverwrite );
        Serial1.println("\nBlocked");
        #ifdef PRINT_DISABLE_STATUS
        Serial.println("CC OFF by SAFECAR");
        #endif
      }
      /* if CCDisable is LOW then CC ON */
      if(_current_state == LOW)
      {
        /* send CC ON notification */
        xTaskNotify(cc_handler,0x03, eSetValueWithOverwrite );
        digitalWrite(StatePin, HIGH);
        #ifdef PRINT_DISABLE_STATUS
        Serial.println("CC ON by SAFECAR");
        #endif
      }
    } /* end if any change */
  } /* end if change after debounceDelay */
  _last_state = _reading_state;

      if (readSerialBluetooth(readingString) > 0)
      {
        if (strcmp("suspender",readingString) == 0)
          {
              xTaskNotify(cc_handler,0x04, eSetValueWithOverwrite );
              Serial1.print("s");
              Serial1.println(SUSPEND_STATE);
          }
        else
          if(strcmp("normal", readingString) == 0)
              {
                for(int i=0 ; i<3 ; i++)
                {
                  digitalWrite(BuzzerPin, HIGH);
                  vTaskDelay(pdMS_TO_TICKS(50));
                  digitalWrite(BuzzerPin, LOW);
                  vTaskDelay(pdMS_TO_TICKS(100));
                }
                EEPROM.update(stateAddress, NORMAL_STATE);
                Serial1.print("s");
                Serial1.println(NORMAL_STATE);
                restartHW();
              }
              else
                if(strcmp("estado", readingString) == 0)
                {
                  switch (EEPROM.read(stateAddress))
                   {
                      case NORMAL_STATE:
                       Serial1.print("s");
                       Serial1.println(NORMAL_STATE);
                       break;
                      case SUSPEND_STATE:
                      Serial1.print("s");
                       Serial1.println(SUSPEND_STATE);
                       break;
                      case BLOCKED_STATE:
                      Serial1.print("s");
                       Serial1.println(BLOCKED_STATE);
                       break;
                       case JAMMED_STATE:
                       Serial1.print("s");
                       Serial1.println(JAMMED_STATE);
                       break;
                      default:
                      Serial1.print("s");
                       Serial1.println(UNKNOWN_STATE);
                       break;
                    }
                }
                else
                  if (strcmp("bloquear",readingString) == 0)
                  {
                    digitalWrite(LedPin,LOW);
                    EEPROM.update(stateAddress, BLOCKED_STATE);
                    #ifdef PRINT_PROTOCOL_STATUS
                    Serial.println("vCCTask notification");
                    #endif

                    /* send CC on notification */
                    xTaskNotify(cc_handler,0x03, eSetValueWithOverwrite );
                    digitalWrite(StatePin, HIGH);
                    Serial1.print("s");
                    Serial1.println(BLOCKED_STATE);
                  }
                  else
                    if (strcmp("version",readingString) == 0)
                    {
                      Serial1.print("v");
                      Serial1.println(VERSION);
                    }
                    else
                      Serial1.println("No command available");
      }

  } /* end for (;;) */
}

//-----------------------------------------------------------------------------
/* This task check the igntion status and  send notitfication to
 * activate/deactivate  vProtocolTask */
static void vIgnitionNotification(void *pvParameters) {

  long c_engine_on = 0;                            /* engine on counter */
  long c_engine_off = 0;                           /* engine off counter */
  TickType_t xLastWakeTime = xTaskGetTickCount();  /* counter initialize */
  TickType_t xFrequency = pdMS_TO_TICKS(1000);     /* frecuency of the task */
  #ifdef IGNITION_FREE_BYTES
  UBaseType_t uxHighWaterMark;
  #endif
  for  (;;) {

    #ifdef IGNITION_FREE_BYTES
    Serial.print("IgntionFreeWords ");
    uxHighWaterMark = uxTaskGetStackHighWaterMark(ignition_handler);
    Serial.println(uxHighWaterMark);
    vTaskDelay(pdMS_TO_TICKS(5000));
    #endif
    /* wait 1 second */
    vTaskDelayUntil(&xLastWakeTime, xFrequency);
    /* if ignition is activated */

    if(digitalRead(IgnitionPin) == LOW)
    {
      /* check if the door is open */
      #ifndef DOORSENSOR /* for automotive sensor and positive/negative sensor*/
      if(digitalRead(DoorPin) == LOW || digitalRead(DoorPositivePin) == LOW){
      #endif
      #ifdef DOORSENSOR /* for magnetic sensor */
      if(digitalRead(DoorPin) == HIGH){
      #endif
      /* activate buzzer */
        digitalWrite(BuzzerPin, HIGH);
        vTaskDelay(pdMS_TO_TICKS(50));
        digitalWrite(BuzzerPin, LOW);
    }
      #ifdef PRINT_IGNITION_STATUS
      if(c_engine_on <= TIME_AFTER_START)
      {
        if(c_engine_on % 5 == 0)
        {
        Serial.print("Ignition ON ");
        time(c_engine_on);
        }
      }
      else
        if( c_engine_on % 60*5 == 0 )
        {
          Serial.print("Ignition ON ");
          time(c_engine_on);
        }
      #endif

      if(c_engine_on == TIME_AFTER_START)
      {
        /* Notify vProtocolTask ON because engine is supose to be on */
          xTaskNotify(protocol_handler,0x01, eSetValueWithOverwrite );
          #ifdef PRINT_IGNITION_STATUS
          Serial.println("Protocol Task notification");
          #endif
      }
        c_engine_on++;
        c_engine_off = 0;
    }  /* end igtion on */
    else
    { /* if ignition off */

      /* if ingtion is on by some time */
      if(c_engine_off == TIME_AFTER_STOP)
      {
        xTaskNotify(protocol_handler,0x02, eSetValueWithOverwrite );
        #ifdef PRINT_IGNITION_STATUS
        Serial.println("Protocol Task notification");
        #endif
      }

      #ifdef PRINT_IGNITION_STATUS
      if(c_engine_off <= TIME_AFTER_STOP)
      {
        Serial.print("Ignition OFF ");
        time(c_engine_off);
      }
      else
        if(c_engine_off % 60 == 0)
        {
          Serial.print("Ignition OFF ");
          time(c_engine_off);
        }
      #endif

        /* counter ingnition off */
        c_engine_on = 0;
        c_engine_off++;
      } /* end engine off*/

    } /* end for (;;)*/
  }
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

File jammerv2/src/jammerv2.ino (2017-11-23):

#include <Arduino_FreeRTOS.h>

#include<CountUpDownTimer.h>


CountUpDownTimer Jam(UP, LOW); // Default precision is HIGH, but you can change
CountUpDownTimer JAMAlert(UP, LOW); // Default precision is HIGH, but you can change it to also be LOW
CountUpDownTimer Door1(UP, LOW); // Default precision is HIGH, but you can change it to also be LOW
CountUpDownTimer Libre(UP, LOW); // Default precision is HIGH, but you can change it to also be LOW
int t_jam = 30;     // Jamming time in minutres
int t_door = 30;    // door open time in minutres

#define CCPIN          3    // Corta corriente
#define LEDPIN         4    // Relay pin 1 on/off
#define JAMPIN         5    // JAmming detector open/gnd
#define DOOR1PIN       7    // Door switch open/gnd
#define DOOR2PIN       12    // Door switch Vcc/open
#define STARTPIN       14   // restart engine

#define JAM1TOUT       10    // time to shotdowown the the engine in secs
#define J_TIMEOUT_SECS 30    // time to shutdown the engine in min
#define J_TIMEOUT_MIN   1
#define M_TIMEOUT_SECS 30    // tiempo para activar el motor después del jamming
#define M_TIMEOUT_MIN   6
// the setup function runs once when you press reset or power the board
boolean toggle = false;
//Variables de estado
bool JAMMER;
bool CC_ESTADO;
int j_counter = 0;


#include <OneWire.h>
#define ILEDPIN 10
#define READPIN 15
#define WRITEPIN 16
byte key_to_write[] = { 0x01, 0x00, 0x3E, 0x5C, 0x03, 0x00, 0x00, 0x35 };
OneWire  ds(READPIN);

// define two tasks for Blink & JammerRead
void TaskBlink( void *pvParameters );
void TaskJammerRead( void *pvParameters );
void TaskIbuttonRead( void *pvParameters);
void TaskIbuttonWrite( void *pvParameters);
// the setup function runs once when you press reset or power the board


#include "OneWireHub.h"
#include "DS2401.h"  // Serial Number

constexpr uint8_t pin_led       { ILEDPIN };
constexpr uint8_t pin_onewire   { WRITEPIN };

auto hub     = OneWireHub(pin_onewire);
auto ds1990A = DS2401( DS2401::family_code, 0x88, 0xC4, 0x07, 0x18, 0x00, 0x00 );



void setup() {

  // initialize serial communication at 9600 bits per second:
  Serial.begin(9600);

  /*
  while (!Serial) {
  ; // wait for serial port to connect. Needed for native USB, on LEONARDO, MICRO, YUN, and other 32u4 based boards.
}
*/
// Now set up two tasks to run independently.
xTaskCreate(
  TaskBlink
  ,  (const portCHAR *)"Blink"   // A name just for humans
  ,  128  // This stack size can be checked & adjusted by reading the Stack Highwater
  ,  NULL
  ,  0  // Priority, with 3 (configMAX_PRIORITIES - 1) being the highest, and 0 being the lowest.
  ,  NULL );

  xTaskCreate(
    TaskJammerRead
    ,  (const portCHAR *) "JammerRead"
    ,  128  // Stack size
    ,  NULL
    ,  2  // Priority
    ,  NULL );

    xTaskCreate(
      TaskIbuttonRead
      ,  (const portCHAR *) "IbuttonRead"
      ,  128  // Stack size
      ,  NULL
      , 3  // Priority
      ,  NULL );

      xTaskCreate(
        TaskIbuttonWrite
        ,  (const portCHAR *) "IbuttonWrite"
        ,  128  // Stack size
        ,  NULL
        , 3  // Priority
        ,  NULL );

        // Now the task scheduler, which takes over control of scheduling individual tasks, is automatically started.
      }

      void loop()
      {
        // Empty. Things are done in Tasks.
      }

      /*--------------------------------------------------*/
      /*---------------------- Tasks ---------------------*/
      /*--------------------------------------------------*/
      void TaskIbuttonRead(void *pvParameters)  // This is a task.
      {
        (void) pvParameters;


        digitalWrite(ILEDPIN,HIGH);

        byte data[8];

        for(;;){

          vTaskDelay(2000/portTICK_PERIOD_MS);
          if (ds.reset() !=1)
          {
            Serial.print("Esperando por ibutton\n");
            vTaskDelay(3000 / portTICK_PERIOD_MS);
          }
          else {
            printStatus("Reading iButton Key.");
            readKey(data);
            Serial.print("CRC:\t");  Serial.println(OneWire::crc8(data, 7), HEX);
          }
        }
      }

      void TaskIbuttonWrite(void *pvParameters)  // This is a task.
      {
        (void) pvParameters;

        Serial.println("OneWire-Hub DS2401 Serial Number used as iButton");

        pinMode(pin_led, OUTPUT);


        // Test-Cases: the following code is just to show basic functions, can be removed any time
        // ds2401A and B alternate with each LED-Blink-Change, so there is only one online at a time
        // ds2401C is always online

        Serial.println("config done");

        for(;;){
          // following function must be called periodically
          hub.poll();

          // Blink triggers the state-change
          if (blinking())
          {
            static bool flipFlop = 0;
            // Change between Sensor A and B every 50 seconds
            if (flipFlop)
            {
              flipFlop = 0;
              hub.detach(ds1990A);
              Serial.println(".. is inactive");
            }
            else
            {
              flipFlop = 1;
              hub.attach(ds1990A);
              Serial.println(".. is active");
            }
          }
          vTaskDelay(100/portTICK_PERIOD_MS);
        }
      }


      void TaskBlink(void *pvParameters)  // This is a task.
      {
        (void) pvParameters;


        /*
        Blink
        Turns on an LED on for one second, then off for one second, repeatedly.


        by Arturo Guadalupi
        */

        // initialize digital LEDPIN on pin 13 as an output.
        for (;;) // A Task shall never return or exit.
        {

          Serial.print(" Status: ");
          Serial.print(HIGH);
          Serial.print('\t');
          vTaskDelay( 10 / portTICK_PERIOD_MS ); // wait for one second
          Serial.print("\t Status: ");
          Serial.print(LOW);
          Serial.print('\t');
          vTaskDelay( 10 / portTICK_PERIOD_MS ); // wait for one second
        }
      }


      void TaskJammerRead(void *pvParameters)  // This is a task.
      {
        (void) pvParameters;
        pinMode(CCPIN, OUTPUT);
        pinMode(LEDPIN, OUTPUT);


        pinMode(JAMPIN, INPUT_PULLUP);
        pinMode(DOOR1PIN, INPUT_PULLUP);
        pinMode(DOOR2PIN, INPUT_PULLUP);
        pinMode(STARTPIN, INPUT_PULLUP);

        digitalWrite(CCPIN, HIGH);
        digitalWrite(LEDPIN, LOW);

        Jam.StartTimer();
        JAMAlert.StartTimer();
        Door1.StartTimer();
        Libre.StartTimer();

        JAMMER = false;
        /*
        JammerReadSerial
        Reads an analog input on pin 0, prints the result to the serial monitor.
        Graphical representation is available using serial plotter (Tools > Serial Plotter menu)
        Attach the center pin of a potentiometer to pin A0, and the outside pins to +5V and ground.

        This example code is in the public domain.
        */
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

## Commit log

2017-08-24 cambio en el hardware y el código del jammer
    [Safecar.kicad_pcb, Safecar.sch, case.fcstd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]
2017-08-25 update led settings
2017-08-29 new
    copy of jammer1 for freertos implementation
    [jammerv2.ino]
2017-09-04 Escritura ibutton
    Se modifica los pines para poder escribir en otro dispositivo de 3.3 v , falta probar
2017-09-12 new design
    [Safecar.brd, Safecar.sch]
2017-10-26 agregué ibutton y jammer en freertos
    [jammerv2.ino]
2017-11-23 elimina safecar.brd porque el archivo esta malo. Se agrega un nuevo código de lectura del ibuton
    [Arturo_Veras.brd, Arturo_Veras.sch, Safecar.brd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]
2017-11-23 modificaciones de pines para la placa. jammev3 es una versión sin freertos
    [jammerv2.ino, jammerv3.ino]
2017-11-23 No se que hice
    Este codigo funcionó para la comunicación serial
    [Arturo_Veras.brd, Safecar.kicad_pcb, Safecar.sch]
2017-11-28 Simulacion de las entradas y salidas en formato spice
2017-11-28 logos de safecar
2017-11-28 archivos inncesesarios
    [case.fcstd]
2017-12-01 se arreglan los pines para la placa. Se agrega Serial.print para la puerta. Se corrige las salidas para el corta corriente. Se prueba con el LEDPIN pero aún no funciona
    [jammerv3.ino]
2017-12-01 Agregó LEDPIN durante el JAMAlert.
    [jammerv3.ino]
2017-12-01 Actualizo la distribución de pines. Se agregan los archivos GERBER
    [Arturo_Veras.GBL, Arturo_Veras.GBO, Arturo_Veras.GBP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]
2017-12-28 Todo list and software description
    Se borra la lista por hacer.
    Se agrega la descirpcion del algorimo.
2018-01-29 se agrega la notificación cada 10 minutos del dispositivo
2018-02-05 Elinino archivos y codigos innecesarios.
    [Arturo_Veras.GBL, Arturo_Veras.GBO, Arturo_Veras.GBP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]
2018-02-20 Added cut-engine connection without relay
2018-02-20 delay for pin output stabilizer
2018-02-20 added state variables to cut-engine relay or not and the door sensor.
2018-06-05 comienzo de versión 2
    Se agrega nuevos componentes a la placa y se se hace un código con FreeRtos.
    [Arturo_Veras.sch, Arturo_Verasv2.brd, Arturo_Verasv2.sch]
2018-06-06 Hardware update
    se ordena el ciruito para que quede más simple revisar las señales.
2018-06-06 hardware update
    se agregan más componentes
    [Arturo_Verasv2.brd, Arturo_Verasv2.sch]
2018-06-13 Esquematico
    se hace más simple el esquemático
    [Arturo_Verasv2.csv, Arturo_Verasv22.brd, Arturo_Verasv22.sch]
2018-06-21 Se agrega pin
    nuevos pines agregados
2018-06-26 Mejora del Encendido de Motor
    Se mejora la salida del encendido de motor porque.
    Se invierte la salida jammeralert y se quita de la tarea Jammer
    [main.cpp]
2018-06-26 no se que hice
2018-07-13 se agrega el activar el motor cuando se corta por jammer
    [main.cpp]
2018-07-17 Circuito de pruebas
    pruebas de corrientes para transistores
2018-07-17 Cambios en las piezas
    se cambian los transistores, las resistencias y los conectores.
2018-07-17 Más cambios
    más cambios en conectores, transistores y resistencias
    [Arturo_Verasv2.brd]
2018-08-08 Se cambia el nombre del pin
2018-08-14 diseño de tomas
    esta es la versión corregida que entregó tomas y es la que enviamos a fabricar
    [Arturo_Eagle_7_X.brd, Arturo_Eagle_7_X.sch, Arturo_Verasv2.brd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]
2018-08-14 Taskcreate priority
    Se arregla el error de de asignar prioridades mayores a 4 a la creación de las tareas. Además elimina la tarea Door y se junta todo en Ignitionnotificationtask
    [main.cpp]
2018-08-17 taskinterrupt
    se mejora la detección de interrupciones. queda pendiente la activación de la interrupcion por la notifiación de evento.
2018-08-18 Falta arreglar la interrupción que se ejecuta cuando se activa la notificación
    [main.cpp]
2018-08-21 cambie el vPrintStringAndNumber por Serial.print porque da errores.
    [main.cpp]
2018-08-21 Se eliminan algunos print que hacen malfuncionar el programa
2018-08-22 Se arregla el error que genrea las interrupciones!!
    [main.cpp]
2018-09-20 se agrega un tiempo definido en TIME_AFTER_OPEN_DOOR para encender el CC
2018-09-20 Se agrega pin para que funcione con positivo
2018-10-16 se agrega para debug
2018-10-29 se mejora el serial.print
2018-10-29 agrego posibilidad de cambiar para ambos sensores según DOORSENSOR
2018-11-22 se cambia la estructura del código, está malo aún
2018-11-29 Se cambia la estructura completamente. versión funcional, falta probar.
2018-12-13 se agrega el id por bluetooth. Falta que hacer para reiniciar con el baudrate normal.
2018-12-18 Se agrega función de bloquear con bluetooth. Falta probar
2018-12-20 se agrega variable no volatil al estado del jammer.
    [main.cpp]
2019-05-08 se agrega el estado y la versión
2019-05-31 todas las tareas funncionan por separado, falta reajustar el heap Size
2019-05-31 buscando el stack perfecto
2019-06-04 reduzco el configMINIMAL_STACK_SIZE, hago mejoras en el código
2019-06-20 Se elimina el cambio del corta corriente por la entrada CCDisable
2019-07-08 mejoras en el desbloqueo por gps
2019-07-24 Se maneja la excepción del buffer para el seria1 read
2019-07-26 cambios en el bluetooth
2019-08-07 se agregan estados y se mejora la config por bluetooth
2019-08-19 se agrega nuevo estado para acceder más rápido a la app.
2019-09-16 se agrega la puerta
2019-11-20 se agrega testtask
    tarea para probar las entradas y salidas del AJ
2019-11-21 output pin
    se agregan los pin de salida
2019-11-26 se termina la primera version del testtask
2020-02-05 codigo más limpio y mejoras en la tareas Test
2020-03-06 version de pruebas sin la tarea Test
2020-03-09 agrego comando memtest para revisar memoria y se mejoran algunos print
2020-03-13 mejoras para evitar que se quede pegado
2020-03-13 quité el timer de la memoria, más estable
2020-03-18 aún se queda pegado el corta corriente.
2020-03-18 se agrega el codigo para leer memoria
2020-03-19 siguen en pruebas, falla el corta corriente
2020-03-25 se agrega la funciona F() y mejora la establidad, aún en pruebas
2025-08-27 merge: Integrate documentation from optimization branch
    - Add comprehensive CHANGELOG.md with complete version history
    - Add detailed RELEASE_NOTES.md for current state
    - Update README.md with professional structure and documentation
    - Preserve master branch stability while adding documentation improvements

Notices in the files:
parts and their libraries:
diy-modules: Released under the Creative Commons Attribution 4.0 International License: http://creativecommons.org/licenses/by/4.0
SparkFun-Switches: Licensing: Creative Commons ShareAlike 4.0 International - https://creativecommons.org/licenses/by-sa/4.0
